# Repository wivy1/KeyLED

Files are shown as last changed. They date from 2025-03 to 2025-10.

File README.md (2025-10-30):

# KeyLED - a DIY music composition and improvisation aid
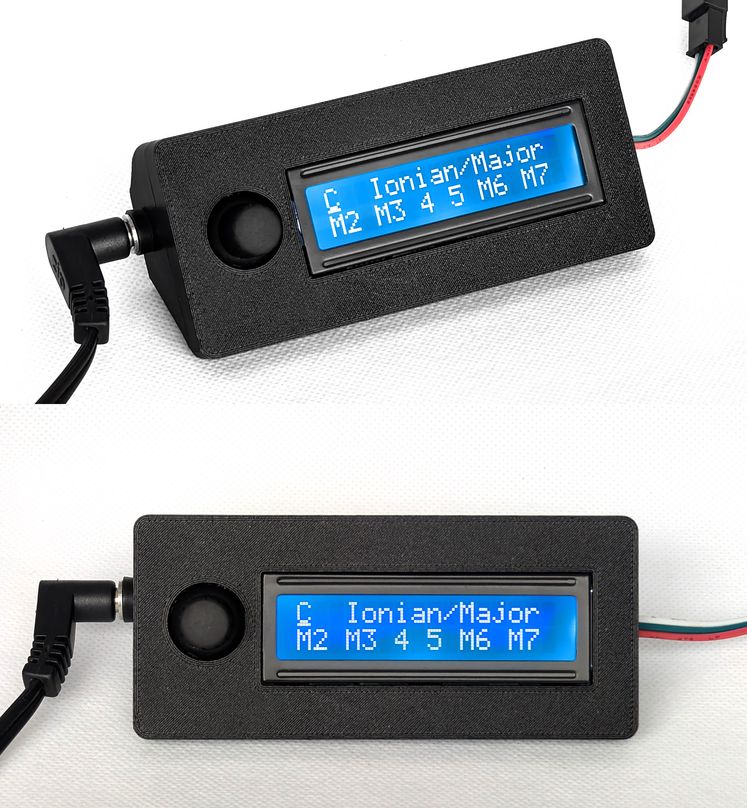
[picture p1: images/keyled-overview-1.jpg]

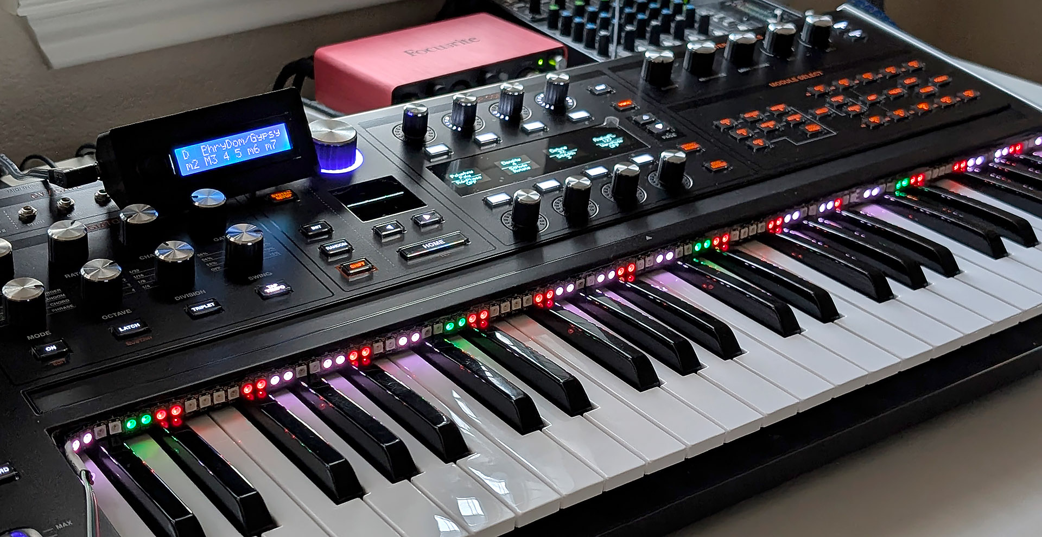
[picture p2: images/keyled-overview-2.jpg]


## Description

KeyLED illuminates the keys of any musical keyboard according to a user-selected root note and scale/mode. It provides visual cues for scales/modes, intervals, and root notes — ideal for both novice keyboardists looking to learn scales and experienced musicians who want to expedite composition and improvisation. 

Designed to be modular, KeyLED can be configured for any keyboard length and key width, and can be assembled using readily available (and cheap!) components inside a simple 3D-printed enclosure.

---

## Features
- **Built-in Scale/Mode Library** - 19 scales and modes to cover all genres and styles of music
- **Modular Design** - can be configured for any keyboard length (25 keys to 100+ keys) and key widths
- **Easy to DIY** - uses common and cheap electrical components and a 3d-printed case, with all design files provided (schematics, models, firmware, etc.)
- **Intuitive Interface** - a single rotary knob for selecting root note and scale, as well as device configuration

---

## How to Use

1. Attach LED strip to keyboard using 3d-printed plastic clips or backing adhesive
2. Select Root Note, press rotary knob
3. Select Scale/Mode
4. Play!

To configure a new keyboard:

1. Long-press rotary knob to enter configuration menu
2. Rotate rotary knob to desired parameter, press rotary knob to select
3. Rotate rotary knob to change parameter, press rotary knob to accept, repeat until all parameters configured
4. Long-press rotary knob to exit configuration menu

---

## Demonstrations (click to play)

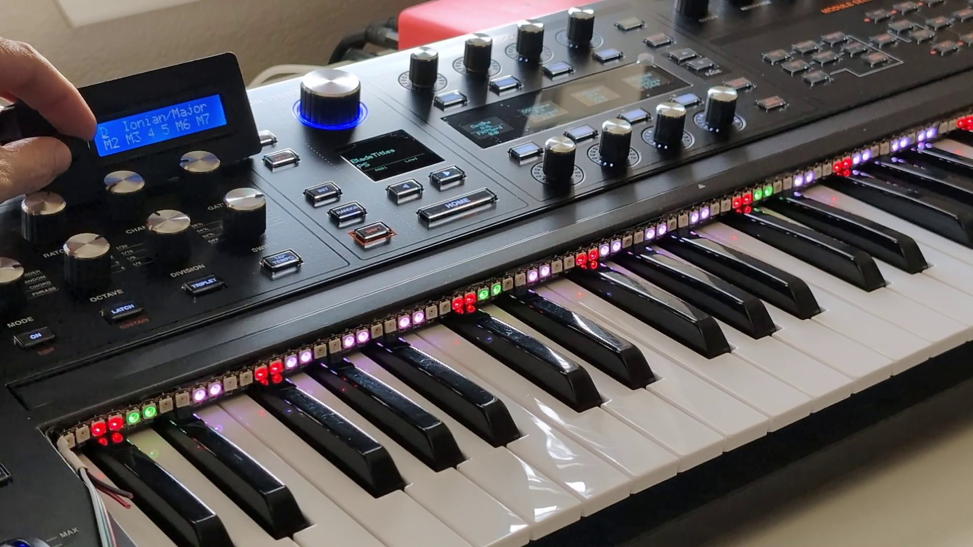
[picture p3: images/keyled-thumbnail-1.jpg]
(https://www.youtube.com/watch?v=ERQJ_ipnesM)
Changing scale and root note: 

Configuring a new keyboard:
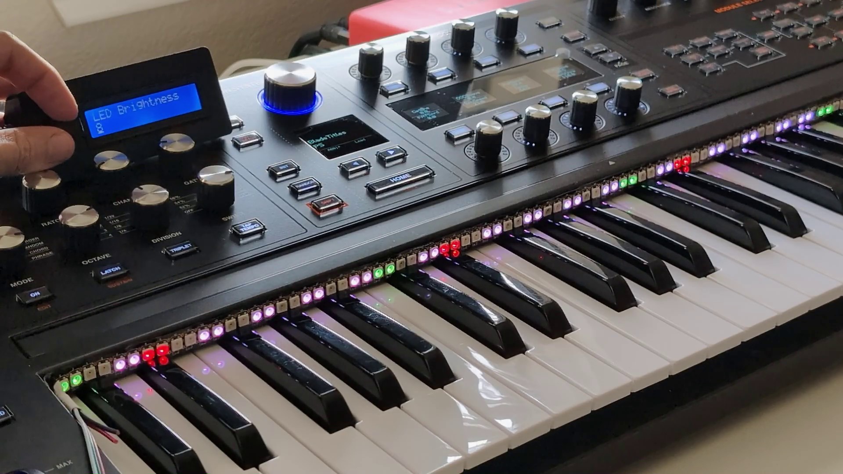
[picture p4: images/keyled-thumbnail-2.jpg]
(https://www.youtube.com/watch?v=EnNY4Os5I3w)


Playing around with scales, [Vangelis](https://en.wikipedia.org/wiki/Vangelis)-style:
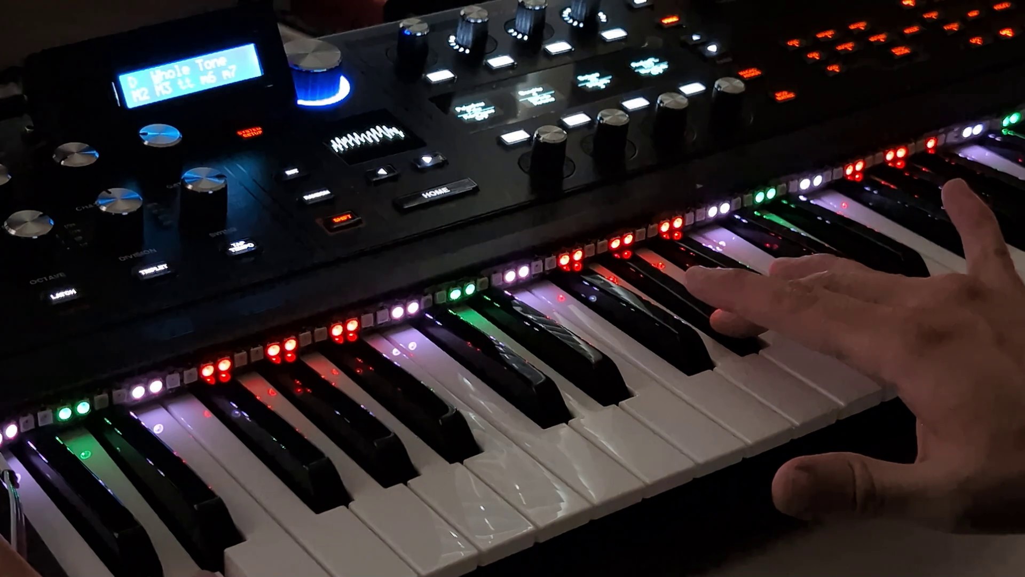
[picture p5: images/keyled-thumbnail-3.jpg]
(https://www.youtube.com/watch?v=hRMsHAzw57w)


---

Thank you for checking out KeyLED! If you find the device useful, please [reach out](mailto:contact@williamivy.com) and let me know.

For a detailed blog post describing the design process, go [here](https://www.williamivy.com/posts/keyled/).

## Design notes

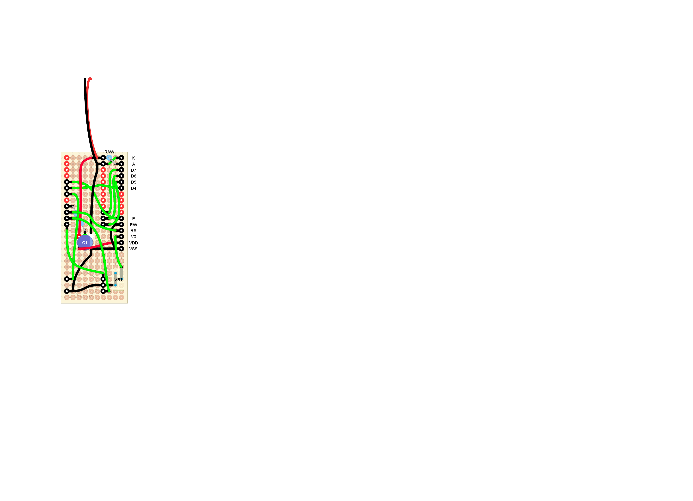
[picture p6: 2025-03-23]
electronics/protoboard.png

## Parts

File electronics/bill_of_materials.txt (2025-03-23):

1x Pro Micro 5V 16MHz ATMEGA32U4 Microcontroller Board
1x 1602 16x2 Character LCD Display Module
1x 5-pin Rotary Encoder with Switch EC11 20mm
1x 3362 1/4" Square Trimpot
1x 1000uF 25V Electrolytic Capacitor
1x 470R Resistor
1x 7cm x 3cm Protoboard
1x 2.54mm Pin Header Male
1x 3-pin JST-SM Connector Male
1x 5V 1A DC Power Supply Adapter with 2.5mm Barrel Tip
1x 2.5mm DC Barrel Jack
1 meter (or more) of WS2812B Individually Addressable Programmable RGB LED Strip (5050 LED, 144LEDs/m density)

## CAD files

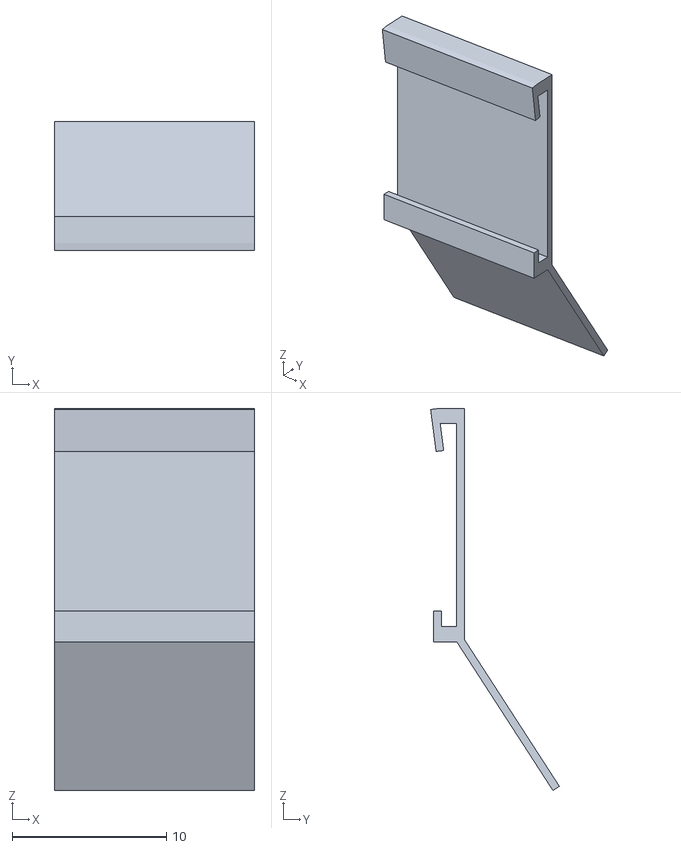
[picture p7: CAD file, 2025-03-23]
3d_printing_files/strip_clip.stl
13.0 x 8.36 x 24.8

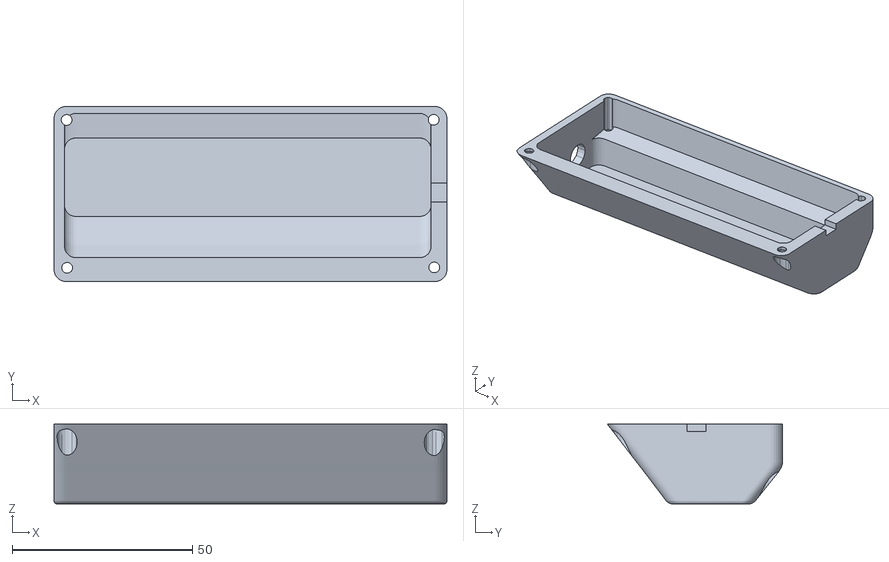
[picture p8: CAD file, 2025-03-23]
3d_printing_files/enclosure_back.stl
109.0 x 48.6 x 22.1

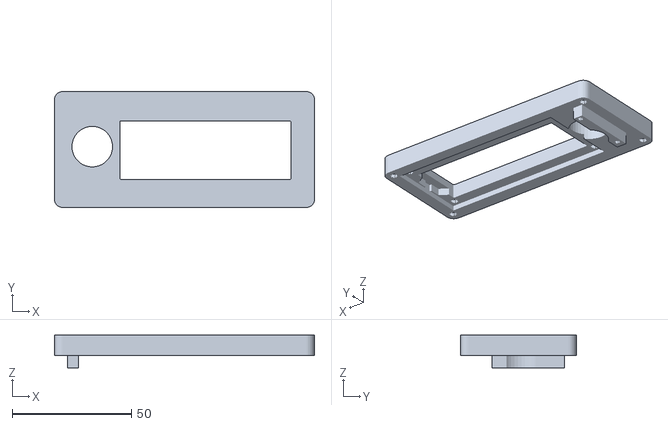
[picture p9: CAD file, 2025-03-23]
3d_printing_files/enclosure_front.stl
109.0 x 48.6 x 13.8

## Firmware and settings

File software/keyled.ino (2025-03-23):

//note numbering scheme:
//  A  A#  B  C  C#  D  D#  E  F  F#  G  G#
//     Bb        Db     Eb        Gb     Ab
//  0  1   2  3  4   5  6   7  8  9   10 11

#include <FastLED.h>
#include <EEPROMex.h>
#include <LiquidCrystal.h>
#include <Rotary.h>

// LED
const byte MAX_LEDS = 500; //to avoid dynamic memory allocation, we will put a hard cap on the maximum number of LEDS, limited by the RAM of the atmega
const byte DATA_PIN = 6; // pin used for data line
const unsigned long int ROOT_COLOR = 0x42FF00;
const unsigned long int WHITE_KEY_COLOR = 0xFFFFFF;
const unsigned long int BLACK_KEY_COLOR = 0xFF0000;
CRGB leds[MAX_LEDS]; //stores the states of the LEDs

// ROTARY ENCODER
Rotary r = Rotary(8, 9);
volatile byte encoderPos = 0; //this variable stores our current value of encoder position. Change to int or uin16_t instead of byte if you want to record a larger range than 0-255

// EEPROM
const unsigned long interval = 1000; //interval between checks on eeprom contents
unsigned long previousMillis = 0; //dont want our eeprom writing to happen on each loop iteration
byte rootnote_address;
byte mode_address;
byte init_address;
const byte maxAllowedWrites = 500;

// LCD
const byte rs = 7, en = 2, d4 = 3, d5 = 10, d6 = 16, d7 = 14; // LCD mappings
LiquidCrystal lcd(rs, en, d4, d5, d6, d7);

// BUTTON
const byte BUTTON_PIN = 4; // this is the Arduino pin we are connecting the push button to
byte oldButtonState = HIGH;  // assume switch open because of pull-up resistor
const unsigned long debounceTime = 10;  // milliseconds
const unsigned long holdTime = 1000; //ms, how long to be considered a long hold
unsigned long buttonChangeTime;  // when the switch last changed state
unsigned long buttonPressTime;
boolean buttonPressed = 0;
boolean buttonHeld = 0;
boolean waitingForHold = 0;

// MENUS
const byte NUM_MENUS = 2;
//menu 0 = Mode Menu
//menu 1 = Setup Menu
byte currentMenu; 

const byte NUM_MODE_OPT = 2;
//option 0 = root note
//option 1 = mode selection
byte currentModeOpt; //start on the root selection
byte newModeOpt;

byte currentRootNoteIndex;
byte newRootNoteIndex;

byte currentModeIndex;
byte newModeIndex;
//0 = choosing parameter
//1 = setting parameter

int currentSetupOpt; //start on the first setup option
int newSetupOpt;

const byte NUM_SETUP_MODES = 2;
//mode 0 = set option
//mode 1 = set value
byte currentSetupMode; //start on the first setup option
byte newSetupMode;

byte newSetupOptValue;

//STRUCTS
struct Note {
  char name[3];
  byte number;
};

const Note notes[] =
{
  {"A", 0},
  {"A#", 1},
  {"Bb", 1},
  {"B", 2},
  {"C", 3},
  {"C#", 4},
  {"Db", 4},
  {"D", 5},
  {"D#", 6},
  {"Eb", 6},
  {"E", 7},
  {"F", 8},
  {"F#", 9},
  {"Gb", 9},
  {"G", 10},
  {"G#", 11},
  {"Ab", 11}
};


struct Mode {
  char * name;
  byte steps[11];
  byte numNotes; //number of notes in this mode
  char * intervals; //the tonic intervals of this mode
};

const char IonianNam[] PROGMEM = "Ionian/Major";
const char IonianInt[] PROGMEM = "M2 M3 4 5 M6 M7";
const char DorianNam[] PROGMEM = "Dorian";
const char DorianInt[] PROGMEM = "M2 m3 4 5 M6 m7";
const char PhrygianNam[] PROGMEM = "Phrygian";
const char PhrygianInt[] PROGMEM = "m2 m3 4 5 m6 m7";
const char LydianNam[] PROGMEM = "Lydian";
const char LydianInt[] PROGMEM = "M2 M3 tt 5 M6 M7";
const char MixNam[] PROGMEM = "Mixolydian";
const char MixInt[] PROGMEM = "M2 M3 4 5 M6 m7";
const char AeolianNam[] PROGMEM = "Aeolian/Minor";
const char AeolianInt[] PROGMEM = "M2 m3 4 5 m6 m7";
const char LocrianNam[] PROGMEM = "Locrian";
const char LocrianInt[] PROGMEM = "m2 m3 4 tt m6 m7";
const char MelMinNam[] PROGMEM = "Melodic Minor";
const char MelMinInt[] PROGMEM = "M2 m3 4 5 M6 M7";
const char HarMinNam[] PROGMEM = "Harmonic Min";
const char HarMinInt[] PROGMEM = "M2 m3 4 5 m6 M7";
const char MajPenNam[] PROGMEM = "MajPentatonic";
const char MajPenInt[] PROGMEM = "M2 M3   5 M6";
const char MinPenNam[] PROGMEM = "MinPentatonic";
const char MinPenInt[] PROGMEM = "   m3 4 5    m7";
const char WholeNam[] PROGMEM = "Whole Tone";
const char WholeInt[] PROGMEM = "M2 M3 tt m6 m7";
const char AugNam[] PROGMEM = "Augmented";
const char AugInt[] PROGMEM = "m3 M3 5 m6 M7";
const char ChromNam[] PROGMEM = "Chromatic";
const char ChromInt[] PROGMEM = "";
const char FulDmNam[] PROGMEM = "FulDiminished";
const char FulDmInt[] PROGMEM = "M2m34ttm6M6M7";
const char DomDmNam[] PROGMEM = "DomDiminished";
const char DomDmInt[] PROGMEM = "m2m3M3tt5M6m7";
const char HlfDmNam[] PROGMEM = "HlfDiminished";
const char HlfDmInt[] PROGMEM = "M2 m3 4 tt m6 m7";
const char GypsNam[] PROGMEM = "PhryDom/Gypsy";
const char GypsInt[] PROGMEM = "m2 M3 4 5 m6 m7";
const char Dor4Nam[] PROGMEM = "Dorian #4";
const char Dor4Int[] PROGMEM = "M2 m3 tt 5 M6 m7";

const Mode modes[] =
{
  {IonianNam, {2, 2, 1, 2, 2, 2}, 7, IonianInt},
  {DorianNam, {2, 1, 2, 2, 2, 1}, 7, DorianInt},
  {PhrygianNam, {1, 2, 2, 2, 1, 2}, 7, PhrygianInt},
  {LydianNam, {2, 2, 2, 1, 2, 2}, 7, LydianInt},
  {MixNam, {2, 2, 1, 2, 2, 1}, 7, MixInt},
  {AeolianNam, {2, 1, 2, 2, 1, 2}, 7, AeolianInt},
  {LocrianNam, {1, 2, 2, 1, 2, 2}, 7, LocrianInt},
  {MelMinNam, {2, 1, 2, 2, 2, 2}, 7, MelMinInt},
  {HarMinNam, {2, 1, 2, 2, 1, 3}, 7, HarMinInt},
  {MajPenNam, {2, 2, 3, 2}, 5, MajPenInt},
  {MinPenNam, {3, 2, 2, 3}, 5, MinPenInt},
  {WholeNam, {2, 2, 2, 2, 2}, 6, WholeInt},
  {AugNam, {3, 1, 3, 1, 3}, 6, AugInt},
  {ChromNam, {1, 1, 1, 1, 1, 1, 1, 1, 1, 1, 1}, 12, ChromInt},
  {FulDmNam, {2, 1, 2, 1, 2, 1, 2}, 8, FulDmInt},
  {DomDmNam, {1, 2, 1, 2, 1, 2, 1}, 8, DomDmInt},
  {HlfDmNam, {2, 1, 2, 1, 2, 2}, 7, HlfDmInt},
  {GypsNam, {1, 3, 1, 2, 1, 2}, 7, GypsInt},
  {Dor4Nam, {2, 1, 3, 1, 2, 1}, 7, Dor4Int}
};

const char opt_numkeys[] PROGMEM = "# of keys";
const char opt_firstnote[] PROGMEM = "First note";
const char opt_bright[] PROGMEM = "LED Brightness";
const char opt_lednumtot[] PROGMEM = "# LEDs total";
const char opt_firstled[] PROGMEM = "First LED pos'n";
const char opt_ledperkey[] PROGMEM = "# LEDs per key";
const char opt_skipled1[] PROGMEM = "LED compress A";
const char opt_skipled2[] PROGMEM = "LED compress B";

struct SetupOpt {
  char * text;
  byte val;
  byte defVal;
  byte minVal;
  byte maxVal;
  byte address;
};

SetupOpt SetupOpt[] = 
{
  {opt_numkeys, 61, 61, 1, 155},
  {opt_firstnote, 4, 4, 0, 16},
  {opt_bright, 8, 8, 1, 50},
  {opt_lednumtot, 144, 144, 1, MAX_LEDS},
  {opt_firstled, 1, 1, 1},
  {opt_ledperkey, 2, 2, 1, 3},
  {opt_skipled1, 0, 0, 1},
  {opt_skipled2, 0, 0, 1}
  
};

// keep this updated. This must match the order of the SetupOptp[] array, this allows me to reference options indirectly,
// so I can reorder them logically later and not need to update the references
enum SetupOptions {
  OPT_NUMKEYS,
  OPT_FIRSTNOTE,
  OPT_BRIGHT,
  OPT_LEDNUMTOT,
  OPT_FIRSTLED,
  OPT_LEDPERKEY,
  OPT_SKIPLED1,
  OPT_SKIPLED2
};

//to store the configuration values in eeprom
byte SetupOptAddr[(sizeof(SetupOpt) / sizeof(SetupOpt[0]))];

void updateOutput(boolean forceRefresh = 0) {

  // Modes menu
  if (currentMenu == 0) {

    if (newRootNoteIndex != currentRootNoteIndex || forceRefresh == 1) {
      lcd.setCursor(0, 0);
      lcd.print(notes[newRootNoteIndex].name);
      String tempstring = notes[newRootNoteIndex].name;
      for (int i = 0; i < (2 - tempstring.length()); i++) {
        lcd.print(" ");
      }

      lcd.setCursor(0, 0);
      if (newRootNoteIndex != currentRootNoteIndex) {
        currentRootNoteIndex = newRootNoteIndex;
      }
    }

    if (newModeIndex != currentModeIndex || forceRefresh == 1) {
      lcd.setCursor(3, 0);
      lcd.print(getString(modes[newModeIndex].name));
      String tempstring = getString(modes[newModeIndex].name);
      for (int i = 0; i < (13 - tempstring.length()); i++) {
        lcd.print(" ");
      }

      lcd.setCursor(0, 1);
      lcd.print(getString(modes[newModeIndex].intervals));
      String tempstring2 = getString(modes[newModeIndex].intervals);
      for (int i = 0; i < (16 - tempstring2.length()); i++) {
        lcd.print(" ");
      }

      lcd.setCursor(3, 0);
      if (newModeIndex != currentModeIndex) {
        currentModeIndex = newModeIndex;
      }
    }

    if (newModeOpt != currentModeOpt) {
      switch (newModeOpt) {
        case 0:
          lcd.setCursor(0, 0);
          encoderPos = currentRootNoteIndex;
          break;
        case 1:
          lcd.setCursor(3, 0);
          encoderPos = currentModeIndex;
          break;
        default:
          break;
      }
      currentModeOpt = newModeOpt;
    }
  }

  // Setup menu
  if (currentMenu == 1) {

    if (newSetupOpt != currentSetupOpt || forceRefresh) {
      lcd.clear();
      lcd.setCursor(0, 0);
      lcd.print(getString(SetupOpt[newSetupOpt].text));
      lcd.setCursor(0, 1);
      if (newSetupOpt == OPT_FIRSTNOTE){
        lcd.print(notes[SetupOpt[newSetupOpt].val].name);
      } else {
        lcd.print(SetupOpt[newSetupOpt].val);
      }
      lcd.setCursor(0, 0);
          
      if (newSetupOpt != currentSetupOpt) {
        currentSetupOpt = newSetupOpt;
      }
    }

    if (newSetupMode != currentSetupMode || forceRefresh) {
      switch (newSetupMode) {
        case 0:
          lcd.setCursor(0, 0);
          encoderPos = currentSetupOpt;
          break;
        case 1:
          lcd.setCursor(0, 1);
          encoderPos = SetupOpt[currentSetupOpt].val;
          break;
        default:
          break;
      }
      if (newSetupMode != currentSetupMode) {
        currentSetupMode = newSetupMode;
      }
    }

  }
}


void setup() {
  // for debugging
  Serial.begin(115200); // start the serial monitor link
  lcd.begin(16, 2);

  // set up momentary button
  pinMode (BUTTON_PIN, INPUT_PULLUP); // setup the button pin

  // set up rotary encoder
  r.begin();
  PCICR |= (1 << PCIE0);
  PCMSK0 |= (1 << PCINT4) | (1 << PCINT5);
  sei();

  //initialize system
  EEPROM.setMaxAllowedWrites(maxAllowedWrites);
  rootnote_address = EEPROM.getAddress(sizeof(byte));
  mode_address = EEPROM.getAddress(sizeof(byte));
  init_address = EEPROM.getAddress(sizeof(byte));
  for (int i = 0; i < (sizeof(SetupOpt) / sizeof(SetupOpt[0])); i++) {
    SetupOpt[i].address = EEPROM.getAddress(sizeof(byte));
    if (EEPROM.readByte(init_address) != 1){
      SetupOpt[i].val = SetupOpt[i].defVal;
      EEPROM.writeByte(SetupOpt[i].address, SetupOpt[i].val);
    } else {
      SetupOpt[i].val = EEPROM.readByte(SetupOpt[i].address);
    }    
  }
  if (EEPROM.readByte(init_address) != 1){
    SetupOpt[OPT_SKIPLED1].val = SetupOpt[OPT_LEDNUMTOT].val + 1;
    EEPROM.writeByte(SetupOpt[OPT_SKIPLED1].address, SetupOpt[OPT_SKIPLED1].val);
    SetupOpt[OPT_SKIPLED2].val = SetupOpt[OPT_LEDNUMTOT].val + 1;
    EEPROM.writeByte(SetupOpt[OPT_SKIPLED2].address, SetupOpt[OPT_SKIPLED2].val);
    newRootNoteIndex = 0;
    currentRootNoteIndex = 0;
    newModeIndex = 0;
    currentModeIndex = 0;
  } else {
    newRootNoteIndex = EEPROM.readByte(rootnote_address);
    currentRootNoteIndex = newRootNoteIndex;
    newModeIndex = EEPROM.readByte(mode_address);
    currentModeIndex = newModeIndex;
    encoderPos = newRootNoteIndex; //need to make sure we don't reset the rootnote when we first hit the lcd update
  }
  //set the EEPROM initialization flag so that we don't revert to defaults anymore
  EEPROM.writeByte(init_address,1);  
  FastLED.addLeds<NEOPIXEL, DATA_PIN>(leds, SetupOpt[OPT_LEDNUMTOT].val);
  FastLED.setBrightness(SetupOpt[OPT_BRIGHT].val);
  currentModeOpt = 0;
  newModeOpt = 0;
  currentSetupOpt = 0;
  newSetupOpt = 0;
  currentSetupMode = 0;
  newSetupMode = 0;
  updateOutput(1);
  updateLED();
  lcd.cursor();
  lcd.setCursor(0,0);
}

void loop() {
  rotaryMenu();
  // store current root note and mode to EEPROM, if changed
  unsigned long currentMillis = millis();
  if (currentMillis - previousMillis >= interval) {
    previousMillis = currentMillis;
    if (currentRootNoteIndex != EEPROM.readByte(rootnote_address)) {
      EEPROM.writeByte(rootnote_address, currentRootNoteIndex);
    }
    if (currentModeIndex != EEPROM.readByte(mode_address)) {
      EEPROM.writeByte(mode_address, currentModeIndex);
    }
    for (int i = 0; i < (sizeof(SetupOpt) / sizeof(SetupOpt[0])); i++) {
      byte tempbyte = EEPROM.readByte(SetupOpt[i].address);
      if (tempbyte != SetupOpt[i].val){
        EEPROM.writeByte(SetupOpt[i].address,SetupOpt[i].val);
      }    
    }
  }
}

void rotaryMenu() {
  // Button reading with non-delay() debounce
  byte buttonState = digitalRead (BUTTON_PIN);
  if (buttonState != oldButtonState) {
    if (millis () - buttonChangeTime >= debounceTime) {
      buttonChangeTime = millis ();
      oldButtonState =  buttonState;
      if (buttonState == LOW) {
        buttonPressed = 1;
        waitingForHold = 1;
        buttonPressTime = millis ();
      }
      else {
        buttonPressed = 0;
        waitingForHold = 0;
      }
    }
  }

  if ((waitingForHold) && (millis () - buttonPressTime >= holdTime)) {
    currentMenu = (currentMenu + 1) % NUM_MENUS;
    lcd.clear();
    if (currentMenu==0){
      switch (currentModeOpt) {
        case 0:
          encoderPos = currentRootNoteIndex;
          break;
        case 1:
          encoderPos = currentModeIndex;
          break;
        default:
          break;
      }
    }

    if (currentMenu==1){
      switch (currentSetupMode) {
        case 0:
          encoderPos = currentSetupOpt;
          break;
        case 1:
          encoderPos = SetupOpt[currentSetupOpt].val;
          break;
        default:
          break;
      }
    }
    
    updateOutput(1);
    waitingForHold = 0;
  }

  // Modes menu
  if (currentMenu == 0) {

    // pressing the button cycles through the options
    if (buttonPressed) {
      newModeOpt = (currentModeOpt + 1) % NUM_MODE_OPT;
      updateOutput();
      buttonPressed = 0;
    }

    switch (currentModeOpt) {
      case 0:
        newRootNoteIndex = encoderPos % (sizeof(notes) / sizeof(notes[0]));
        if (newRootNoteIndex != currentRootNoteIndex) {
          updateOutput();
          updateLED();
        }
        break;
      case 1:
        newModeIndex = encoderPos % (sizeof(modes) / sizeof(modes[0]));
        if (newModeIndex != currentModeIndex) {
          updateOutput();
          updateLED();
        }
        break;
      default:
        break;
    }

  }

  // Setup menu
  if (currentMenu == 1) {
    // pressing the button cycles through the modes
    if (buttonPressed) {
      newSetupMode = (currentSetupMode + 1) % NUM_SETUP_MODES;
      updateOutput();
      buttonPressed = 0;
    }

    if (currentSetupMode == 0) {
      newSetupOpt = encoderPos % (sizeof(SetupOpt) / sizeof(SetupOpt[0]));
      if (newSetupOpt != currentSetupOpt) {
        updateOutput();
      }
    }

    if (currentSetupMode == 1) {
      switch (currentSetupOpt) {
        
        case OPT_NUMKEYS:
          newSetupOptValue = encoderPos;
          if (newSetupOptValue > SetupOpt[OPT_NUMKEYS].maxVal){
            newSetupOptValue=SetupOpt[OPT_NUMKEYS].maxVal;
            encoderPos=SetupOpt[OPT_NUMKEYS].maxVal;
          }
          if (newSetupOptValue < SetupOpt[OPT_NUMKEYS].minVal){
            newSetupOptValue=SetupOpt[OPT_NUMKEYS].minVal;
            encoderPos=SetupOpt[OPT_NUMKEYS].minVal;
          }
          if (newSetupOptValue != SetupOpt[OPT_NUMKEYS].val){
            SetupOpt[OPT_NUMKEYS].val = newSetupOptValue;
            updateOutput(1);
            FastLED.clear();
            updateLED();
          }
          break;

        case OPT_FIRSTNOTE:
          newSetupOptValue = encoderPos;
          if (newSetupOptValue > SetupOpt[OPT_FIRSTNOTE].maxVal){
            newSetupOptValue=SetupOpt[OPT_FIRSTNOTE].maxVal;
            encoderPos=SetupOpt[OPT_FIRSTNOTE].maxVal;
          }
          if (newSetupOptValue < SetupOpt[OPT_FIRSTNOTE].minVal){
            newSetupOptValue=SetupOpt[OPT_FIRSTNOTE].minVal;
            encoderPos=SetupOpt[OPT_FIRSTNOTE].minVal;
          }
          if (newSetupOptValue != SetupOpt[OPT_FIRSTNOTE].val){
            SetupOpt[OPT_FIRSTNOTE].val = newSetupOptValue;
            updateOutput(1);
            FastLED.clear();
            updateLED();
          }
          break;
        
        case OPT_BRIGHT:
          newSetupOptValue = encoderPos;
          if (newSetupOptValue > SetupOpt[OPT_BRIGHT].maxVal){
            newSetupOptValue=SetupOpt[OPT_BRIGHT].maxVal;
            encoderPos=SetupOpt[OPT_BRIGHT].maxVal;
          }
          if (newSetupOptValue < SetupOpt[OPT_BRIGHT].minVal){
            newSetupOptValue=SetupOpt[OPT_BRIGHT].minVal;
            encoderPos=SetupOpt[OPT_BRIGHT].minVal;
          }
          if (newSetupOptValue != SetupOpt[OPT_BRIGHT].val){
            SetupOpt[OPT_BRIGHT].val = newSetupOptValue;
            FastLED.setBrightness(SetupOpt[OPT_BRIGHT].val);
            FastLED.show();
            updateOutput(1);
          }
          break;
          
        case OPT_LEDNUMTOT:
          newSetupOptValue = encoderPos;
          if (newSetupOptValue > SetupOpt[OPT_LEDNUMTOT].maxVal){
            newSetupOptValue=SetupOpt[OPT_LEDNUMTOT].maxVal;
            encoderPos=SetupOpt[OPT_LEDNUMTOT].maxVal;
          }
          if (newSetupOptValue < SetupOpt[OPT_LEDNUMTOT].minVal){
            newSetupOptValue=SetupOpt[OPT_LEDNUMTOT].minVal;
            encoderPos=SetupOpt[OPT_LEDNUMTOT].minVal;
          }
          if (newSetupOptValue != SetupOpt[OPT_LEDNUMTOT].val){
            SetupOpt[OPT_LEDNUMTOT].val = newSetupOptValue;
            updateOutput(1);
            FastLED.clear();
            updateLED();
          }
          break;

        case OPT_FIRSTLED:
          newSetupOptValue = encoderPos;
          if (newSetupOptValue > SetupOpt[OPT_LEDNUMTOT].val){
            newSetupOptValue=SetupOpt[OPT_LEDNUMTOT].val;
            encoderPos=SetupOpt[OPT_LEDNUMTOT].val;
          }
          if (newSetupOptValue < SetupOpt[OPT_FIRSTLED].minVal){
            newSetupOptValue=SetupOpt[OPT_FIRSTLED].minVal;
            encoderPos=SetupOpt[OPT_FIRSTLED].minVal;
          }
          if (newSetupOptValue != SetupOpt[OPT_FIRSTLED].val){
            SetupOpt[OPT_FIRSTLED].val = newSetupOptValue;
            updateOutput(1);
            FastLED.clear();
            updateLED();
          }
          break;
                    
        case OPT_LEDPERKEY:
          newSetupOptValue = encoderPos;
          if (newSetupOptValue > SetupOpt[OPT_LEDPERKEY].maxVal){
            newSetupOptValue=SetupOpt[OPT_LEDPERKEY].maxVal;
            encoderPos=SetupOpt[OPT_LEDPERKEY].maxVal;
          }
          if (newSetupOptValue < SetupOpt[OPT_LEDPERKEY].minVal){
            newSetupOptValue=SetupOpt[OPT_LEDPERKEY].minVal;
            encoderPos=SetupOpt[OPT_LEDPERKEY].minVal;
          }
          if (newSetupOptValue != SetupOpt[OPT_LEDPERKEY].val){
            SetupOpt[OPT_LEDPERKEY].val = newSetupOptValue;
            updateOutput(1);
            FastLED.clear();
            updateLED();
          }
          break;

        case OPT_SKIPLED1:
          newSetupOptValue = encoderPos;
          if (newSetupOptValue > SetupOpt[OPT_LEDNUMTOT].val + 1){
            newSetupOptValue=SetupOpt[OPT_LEDNUMTOT].val + 1;
            encoderPos=SetupOpt[OPT_LEDNUMTOT].val + 1;
          }
          if (newSetupOptValue < SetupOpt[OPT_SKIPLED1].minVal){
            newSetupOptValue=SetupOpt[OPT_SKIPLED1].minVal;
            encoderPos=SetupOpt[OPT_SKIPLED1].minVal;
          }
          if (newSetupOptValue != SetupOpt[OPT_SKIPLED1].val){
            SetupOpt[OPT_SKIPLED1].val = newSetupOptValue;
            updateOutput(1);
            FastLED.clear();
            updateLED();
          }
          break;

        case OPT_SKIPLED2:
          newSetupOptValue = encoderPos;
          if (newSetupOptValue > SetupOpt[OPT_LEDNUMTOT].val + 1){
            newSetupOptValue=SetupOpt[OPT_LEDNUMTOT].val + 1;
            encoderPos=SetupOpt[OPT_LEDNUMTOT].val + 1;
          }
          if (newSetupOptValue < SetupOpt[OPT_SKIPLED2].minVal){
            newSetupOptValue=SetupOpt[OPT_SKIPLED2].minVal;
            encoderPos=SetupOpt[OPT_SKIPLED2].minVal;
          }
          if (newSetupOptValue != SetupOpt[OPT_SKIPLED2].val){
            SetupOpt[OPT_SKIPLED2].val = newSetupOptValue;
            updateOutput(1);
            FastLED.clear();
            updateLED();
          }
          break;
        
        default:
          break;
      }
    }    
  }
}
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

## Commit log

2025-03-23 added power components to BOM
2025-03-23 added LED strip to BOM
